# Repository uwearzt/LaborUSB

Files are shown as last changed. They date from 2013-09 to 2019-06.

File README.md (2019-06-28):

# LaborUSB

Adapter for Labor Power Supply to USB i.e. for Raspberry Pi.

The USB connector from the Sparkfun Eagle Library  was used to create the USB
connector for this Library, see
<https://github.com/sparkfun/SparkFun-Eagle-Libraries>

## Overview

Many prototyping boards these days use USB Connectors as Power Source. For easy powering those devices with my DC Power
Supply (or in german "Labornetzteil") i created a adaptor from 4 mm banana plugs to 4 USB Jacks.

Additional benefit is that all types of iThings can be loaded with the Adaptor. The necessary research for loading Apple
devices was done by [Adafruit](https://www.adafruit.com), see their page
about [icharging](https://learn.adafruit.com/minty-boost/icharging).

The device in action:

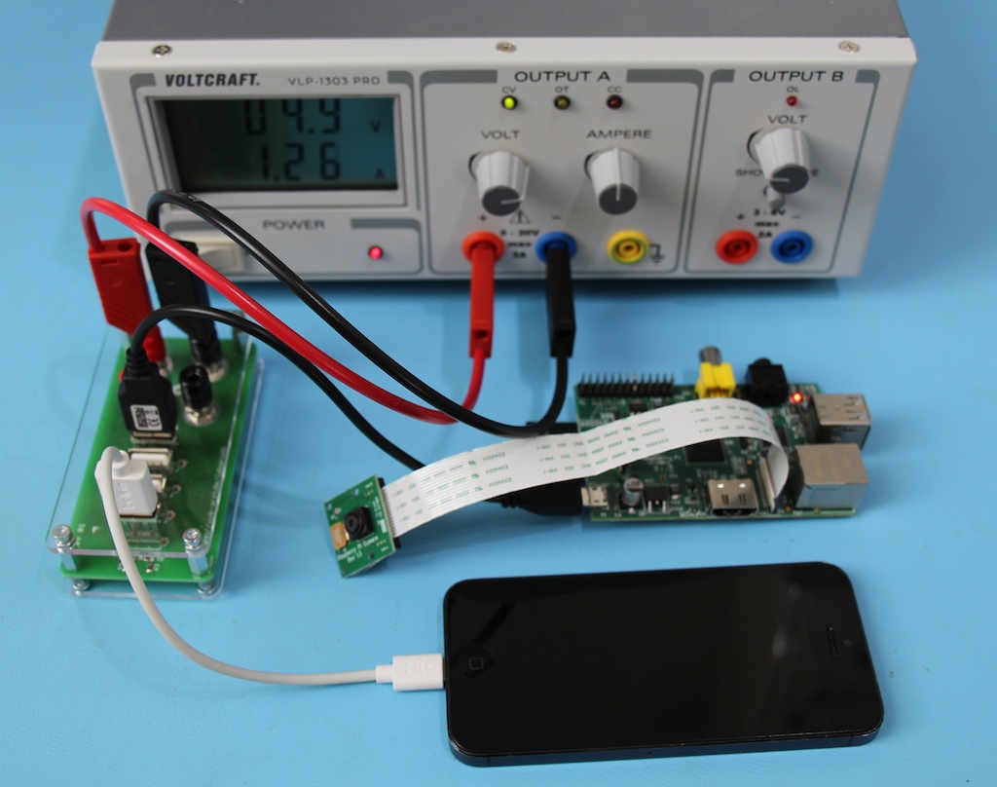
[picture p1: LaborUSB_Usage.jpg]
Usage of LaborUSB


Find all the files necessary to build your own on [GitHub](https://github.com/uwearzt/LaborUSB.git).

I have a few boards available, if you like to build your own, contact me.

<!-- more -->

## Design

### Schematic

The design is really simple and consists of only 4 resistors and 8 jacks. The real work was to make the mechanical dimensions fit for easy and fast assembly.

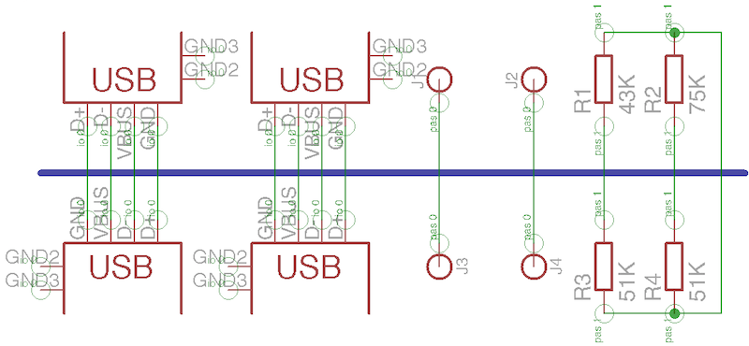
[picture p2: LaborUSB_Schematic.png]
Schematic


### Board

Can be easily done by every board house.

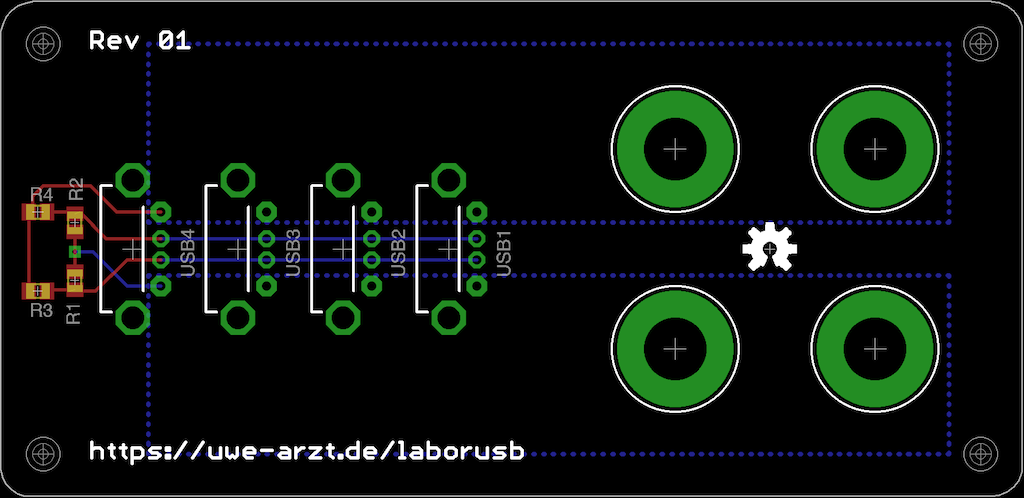
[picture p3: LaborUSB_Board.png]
Board


## Bill of materials

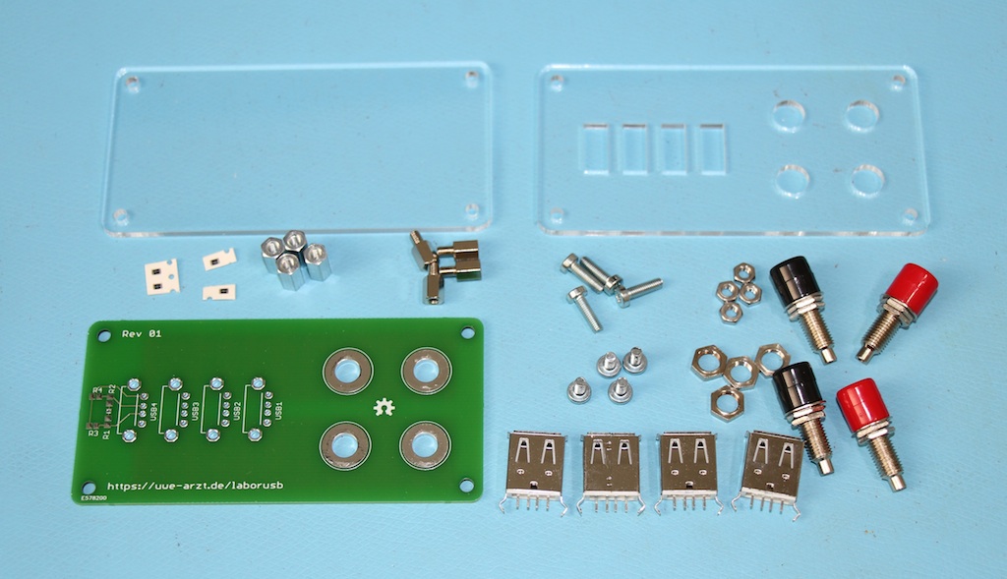
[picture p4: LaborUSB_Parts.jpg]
Parts


<table>
	<thead>
		<tr><th>Count</th><th>Description</th><th>Source</th></tr>
	</thead>
	<tbody>
		<tr><td>2</td><td>Through-hole banana jack Black</td><td><a href="https://www.reichelt.de">Reichelt</a></td></tr>
		<tr><td>2</td><td>Through-hole banana jack Red</td><td><a href="https://www.reichelt.de">Reichelt</a></td></tr>
		<tr><td>1</td><td>Resistor 43K 0805</td><td><a href="https://www.distrelec.de">Distrelec</a></td></tr>
		<tr><td>1</td><td>Resistor 75K 0805</td><td><a href="https://www.distrelec.de">Distrelec</a></td></tr>
		<tr><td>2</td><td>Resistor 51K 0805</td><td><a href="https://www.distrelec.de">Distrelec</a></td></tr>
		<tr><td>4</td><td>USB Jack</td><td><a href="https://www.distrelec.de">Distrelec</a></td></tr>
		<tr><td>1</td><td>Laser cut Front panel 3mm thick</td><td><a href="http://www.formulor.de">Formulor</a></td></tr>
		<tr><td>1</td><td>Laser cut Back panel 3mm thick</td><td><a href="http://www.formulor.de">Formulor</a></td></tr>
		<tr><td>4</td><td>Nuts 6mm Fine Pitch Thread</td><td></td></tr>
		<tr><td>4</td><td>Screws M3 * 6mm</td><td></td></tr>
		<tr><td>4</td><td>Screws M3 * 10mm</td><td></td></tr>
		<tr><td>4</td><td>Hex Standoffs M3 * 12mm without Thread</td><td></td></tr>
		<tr><td>4</td><td>Hex Standoffs * 5mm with Thread</td><td></td></tr>
	</tbody>
</table>

## Assembly

### Solder Resistors

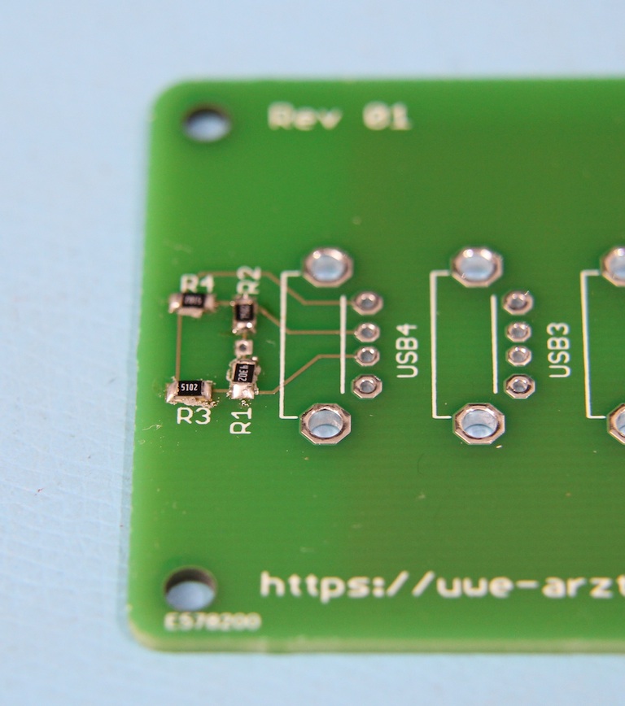
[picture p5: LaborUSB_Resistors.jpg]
Resistors


### Prepare Front Panel

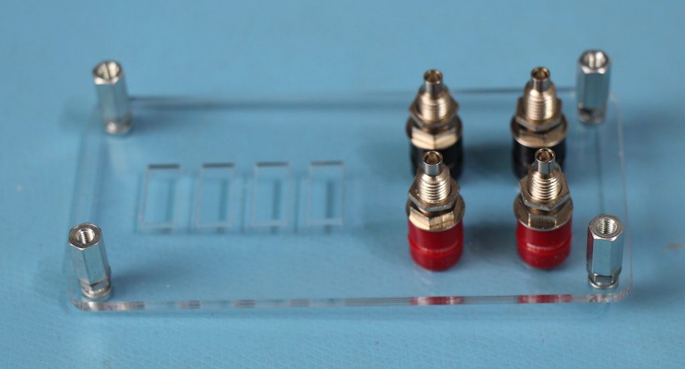
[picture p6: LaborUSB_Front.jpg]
Front


Place the banana jacks in the front panel and secure them with the additional 6mm fine thread nuts. Add one of the delivered 6mm fine thread nuts to every banana plug.

Add the 12mm standoff to the front panel with the M3 10mm screws. If you do not have 12mm standoffs, it is possible to replace the 12mm standoffs with a 10mm standoffs and a additional nuts.

### Add board to front panel

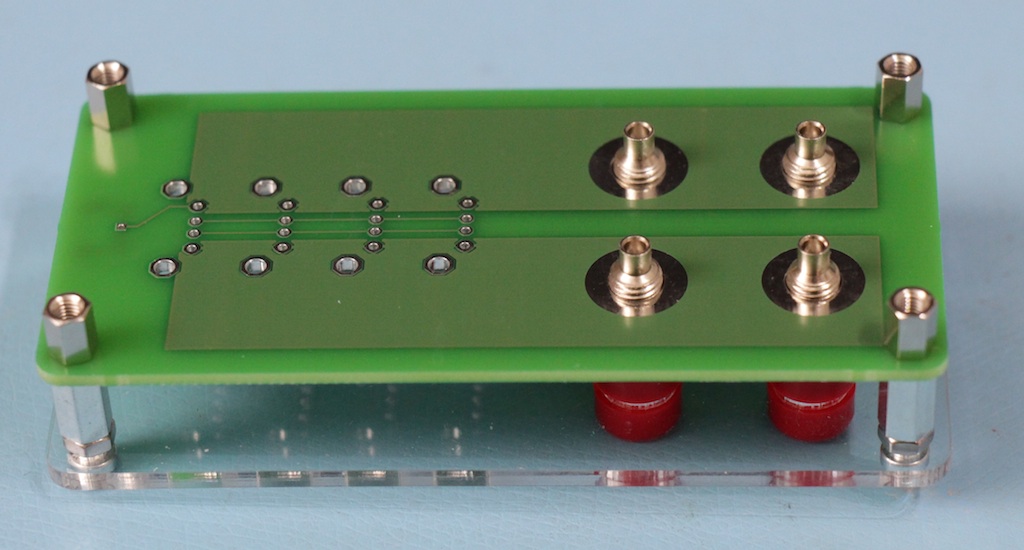
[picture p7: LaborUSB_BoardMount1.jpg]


Place the board on the 12 mm standoff and secure it with the 5mm standoffs.

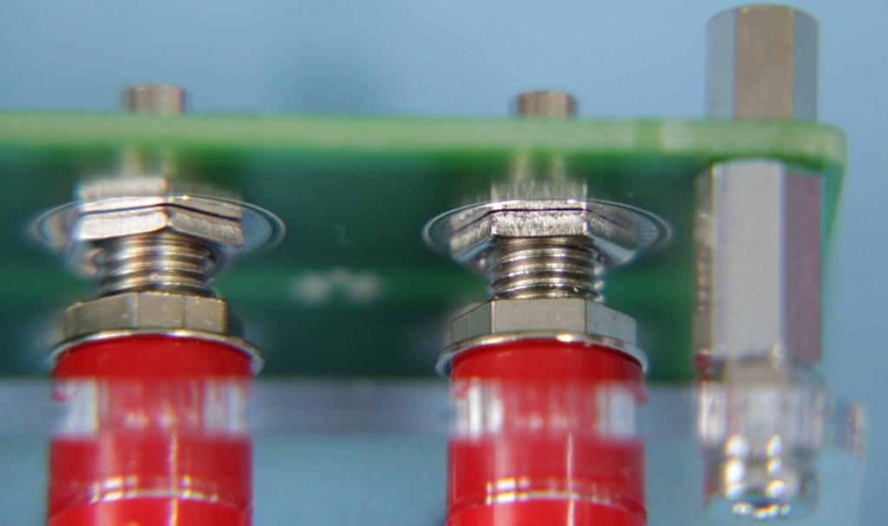
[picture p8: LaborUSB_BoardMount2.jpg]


Screw the 6mm nut up until the board is reached.

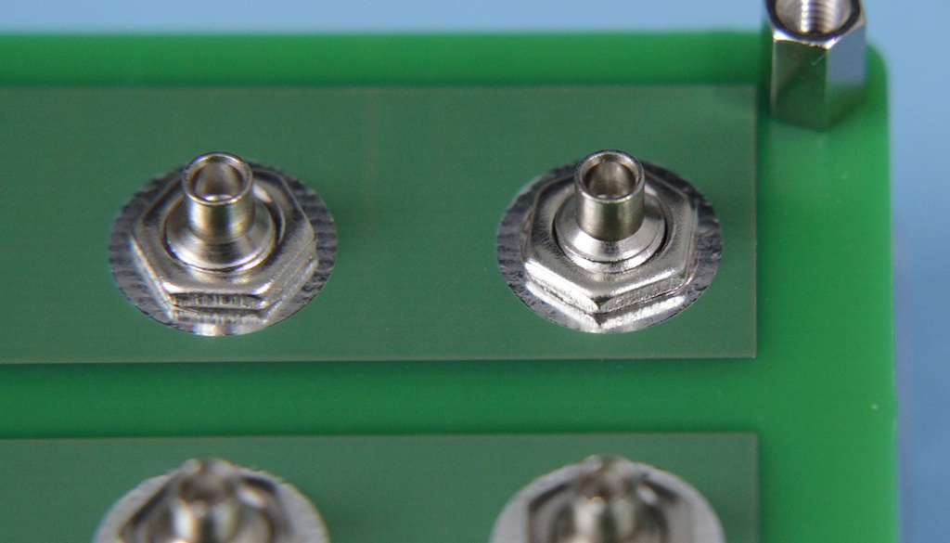
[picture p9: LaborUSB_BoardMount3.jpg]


Take the remaining 6mm fine threaded nuts and secure the banana plugs on the board.

### Add USB Jacks

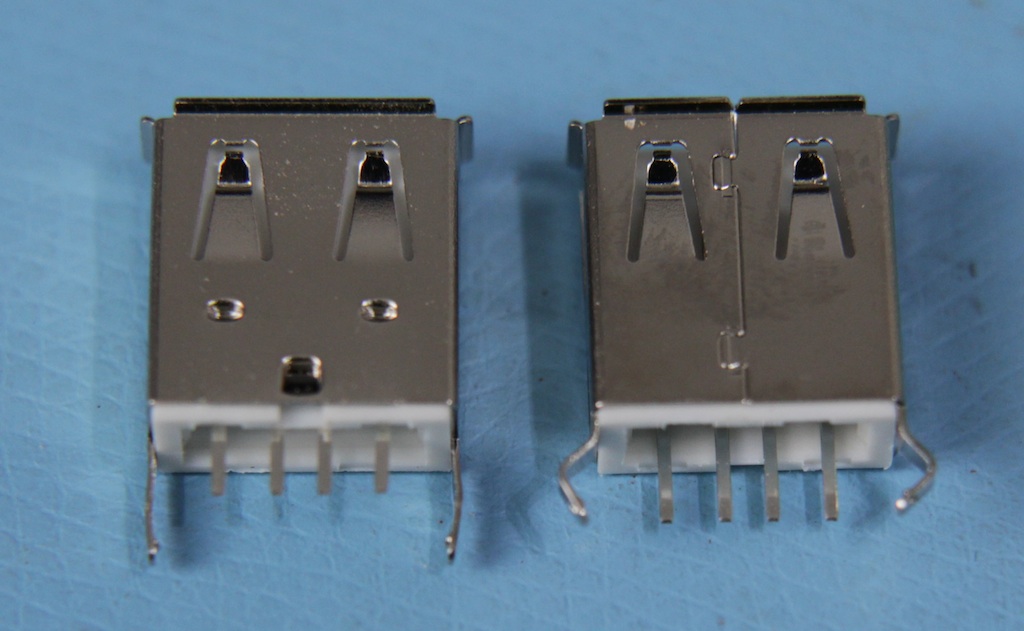
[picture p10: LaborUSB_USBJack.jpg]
USB Jacks


With the USB jacks from Reichelt, you need to first straighten the outer pins as seen on the left jack. Otherwise they will not fit through the front panel.

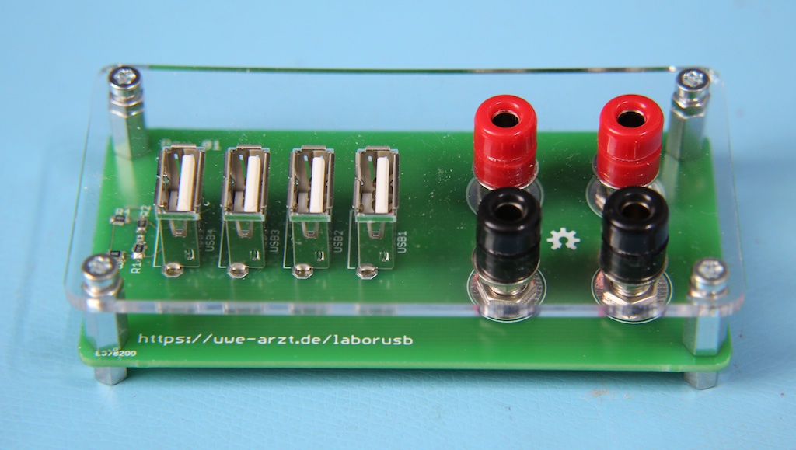
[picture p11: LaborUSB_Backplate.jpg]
Backplate


Place all 4 USB Jacks in the front panel and solder them to the board.

### Add back panel

Use the 4 M3*6 screws and screw the backpanel in place.

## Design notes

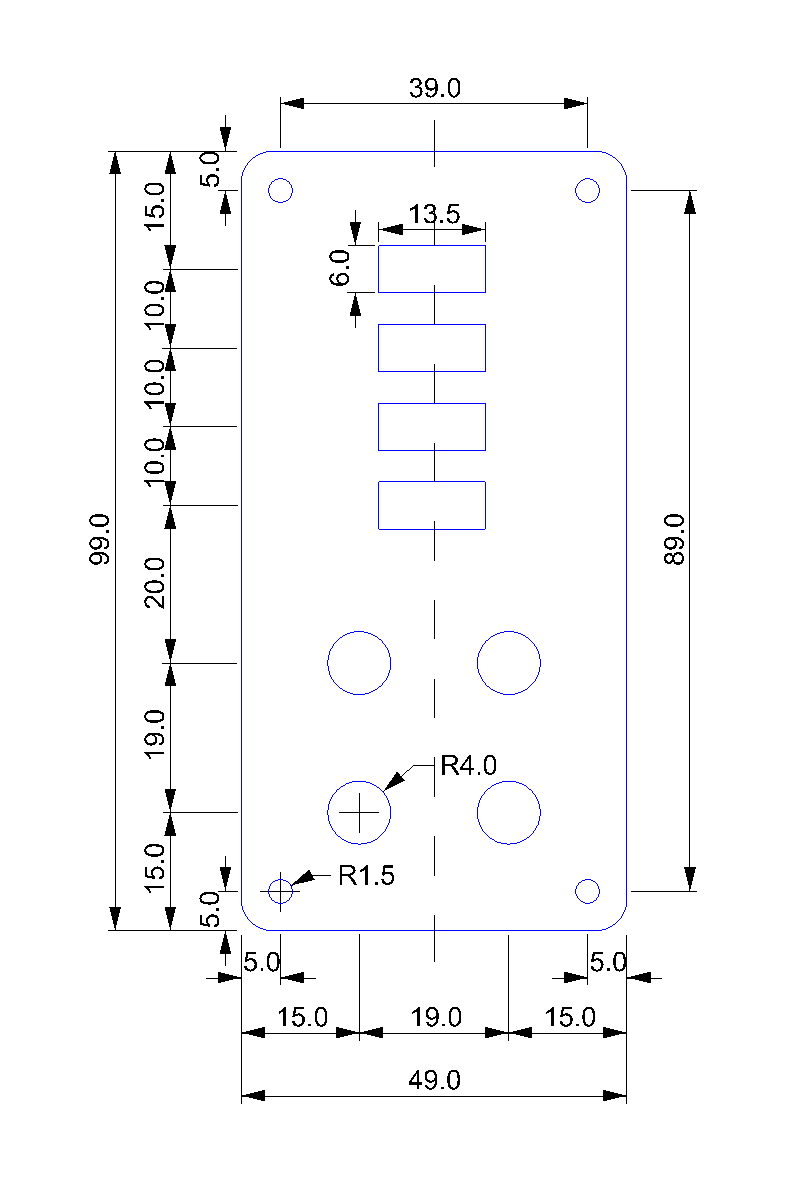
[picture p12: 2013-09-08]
LaborUSB.png

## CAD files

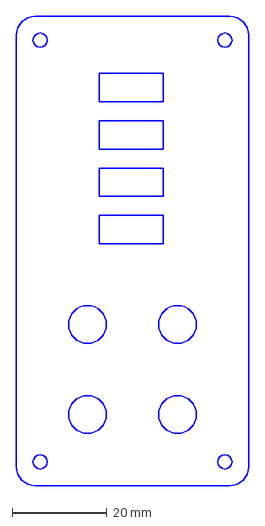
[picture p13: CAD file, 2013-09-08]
LaborUSB_upper.dxf
49.0 x 99.0 mm

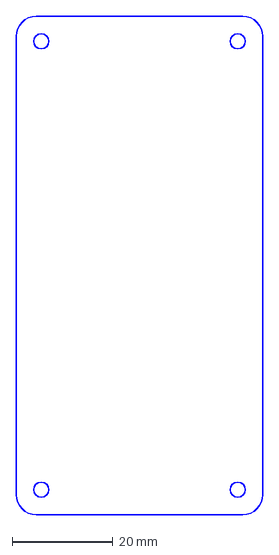
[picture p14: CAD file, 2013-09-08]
LaborUSB_lower.dxf
49.0 x 99.0 mm

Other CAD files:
LaborUSB.3dm

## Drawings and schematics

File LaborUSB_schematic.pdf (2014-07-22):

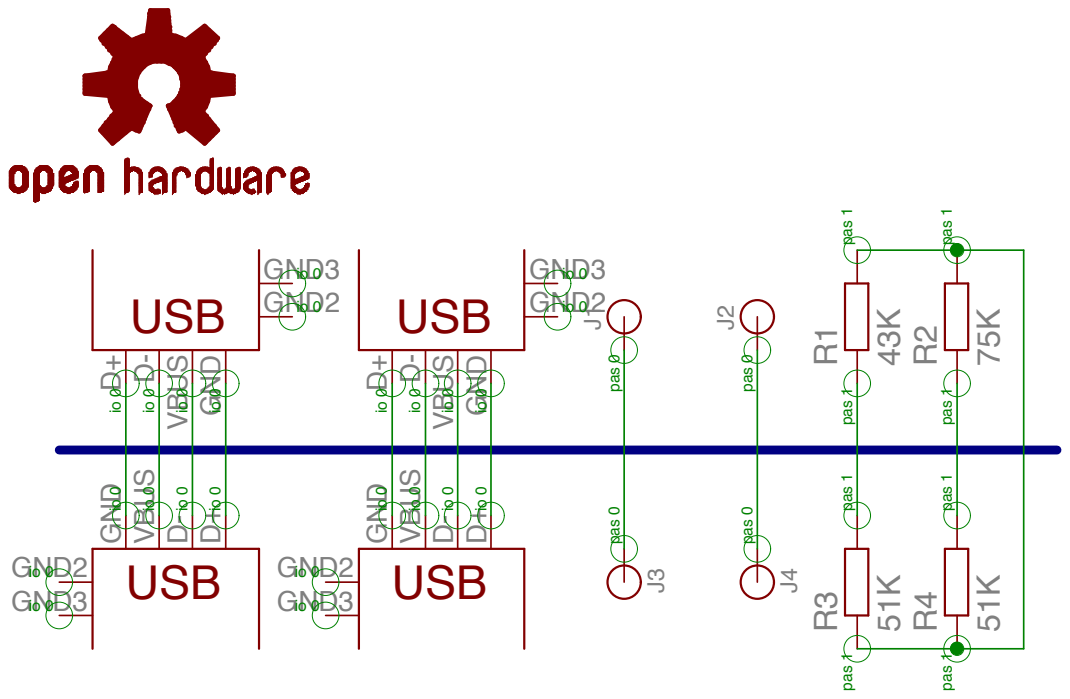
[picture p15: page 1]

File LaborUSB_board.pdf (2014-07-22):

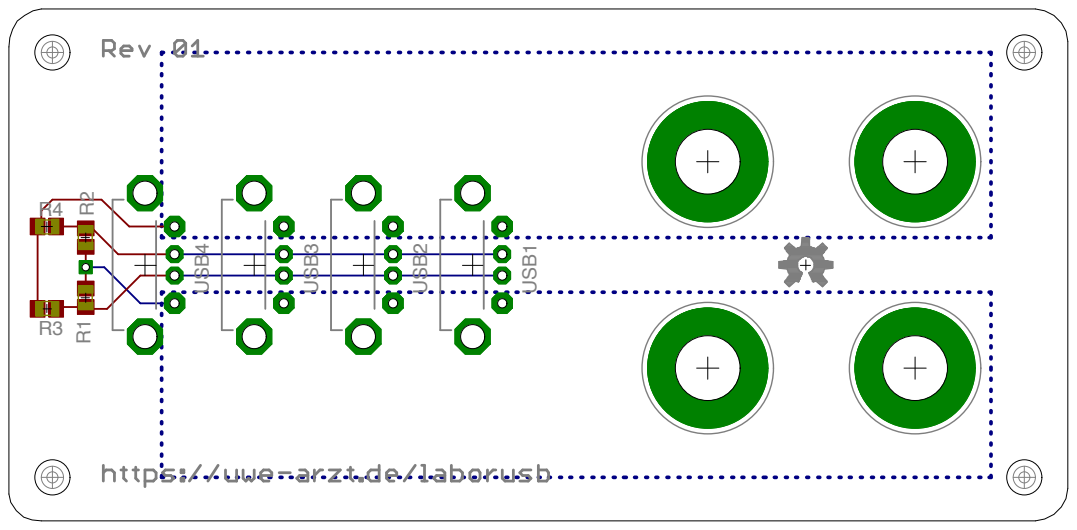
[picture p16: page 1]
USB4; USB3; USB2; USB1

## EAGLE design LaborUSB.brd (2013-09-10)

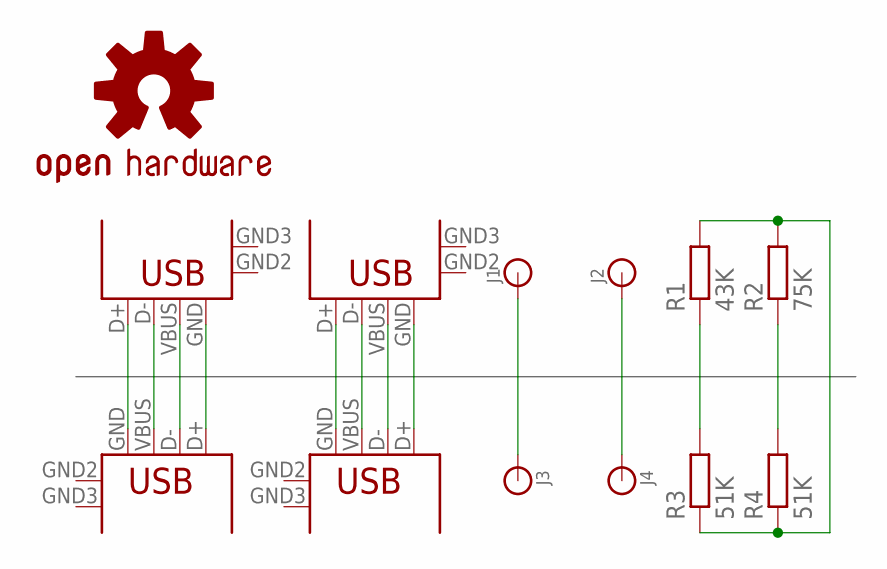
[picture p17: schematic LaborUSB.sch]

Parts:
J1, J2, J3, J4: BANANA
LOGO1: OSHW-LOGOM; OSHW-LOGO-M
R1: 43K; R0805
R2: 75K; R0805
R3, R4: 51K; R0805
USB1, USB2, USB3, USB4: USB+SHIELD; USB-A-VERTICAL

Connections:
D+: R2.1, R4.2, USB1.D+, USB2.D+, USB3.D+, USB4.D+
D-: R1.1, R3.2, USB1.D-, USB2.D-, USB3.D-, USB4.D-
GND: J1.P$1, J2.P$1, R3.1, R4.1, USB1.GND, USB2.GND, USB3.GND, USB4.GND
VBUS: J3.P$1, J4.P$1, R1.2, R2.2, USB1.VBUS, USB2.VBUS, USB3.VBUS, USB4.VBUS

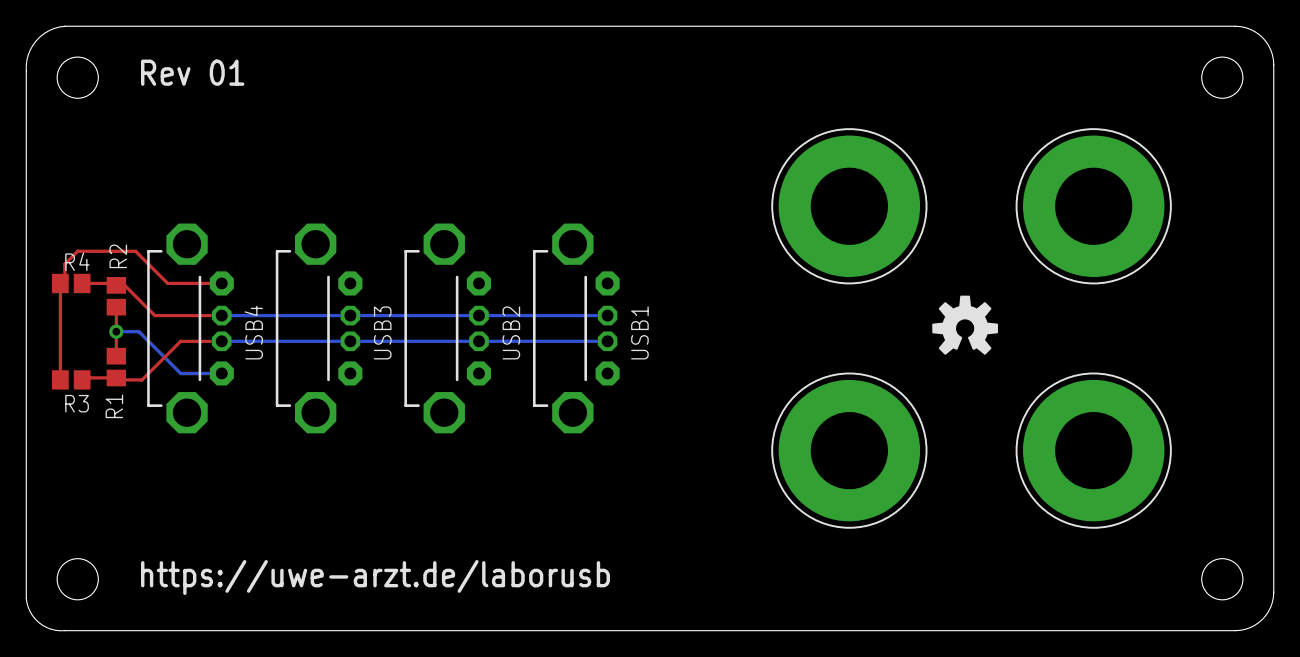
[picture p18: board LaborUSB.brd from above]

Board: 2 copper layers, 97.0 x 47.0 mm, 13 parts (0 on the bottom side), 4 nets.

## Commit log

2013-09-08 Datasheets and Case
    [LaborUSB.3dm, LaborUSB_lower.dxf, LaborUSB_upper.dxf]
2013-09-09 First board to check Library
    [LaborUSB.3dm, LaborUSB.brd, LaborUSB.sch]
2013-09-09 Added iPhone charge capabilty, Component Names
    [LaborUSB.brd, LaborUSB.sch]
2013-09-09 First prototype order
    [LaborUSB.brd, LaborUSB.sch]
2013-09-10 Fix in thermals on Banana Plug
    [LaborUSB.brd, LaborUSB.sch]

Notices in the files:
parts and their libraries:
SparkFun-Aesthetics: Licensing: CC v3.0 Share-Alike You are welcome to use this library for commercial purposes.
